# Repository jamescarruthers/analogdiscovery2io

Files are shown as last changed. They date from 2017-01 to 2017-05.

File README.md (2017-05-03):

# Interface board for Digilent Analog Discovery 2

**Rev-a has been tested and confirmed to work, Rev-b has not been tested yet**

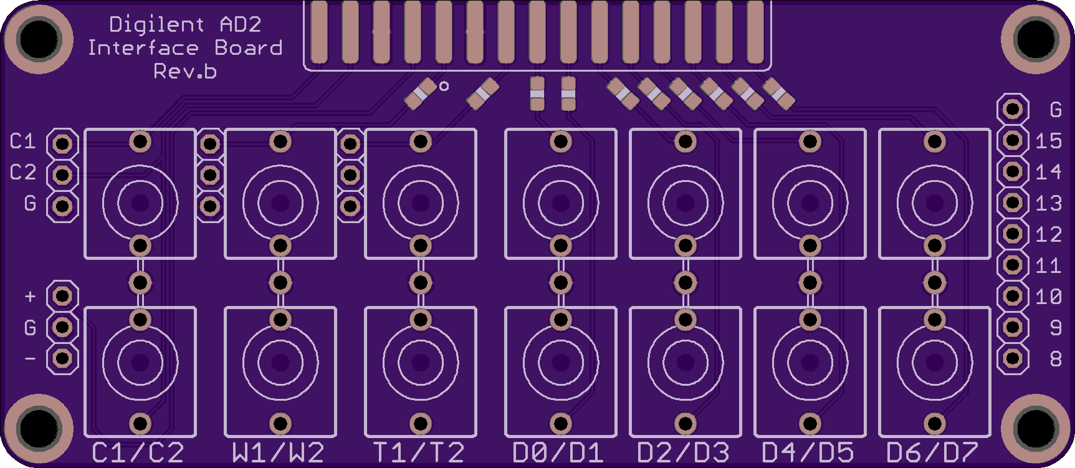
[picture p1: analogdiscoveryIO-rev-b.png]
Board rev-b


A board to interface anything that uses 3.5mm mono jacks (synthesisers etc) with the Digilent Analog Discovery 2 oscilloscope/wave generator/logic analyser.

Provides access to both scope channels, wave generators, triggers plus DIO 0 to 7 via 3.5mm mono jacks. DIO 8 to 15 and V+/V-/Ground via pin headers. The negative differential scope channels are connected to ground.

Note that the wave generator can output -+5V, however the DIO only 3.3V. This board does not implement any kind of level shifting, so if you're testing inputs with the output of the DIO channels then your module needs to work with 3.3V gates/triggers.

Connects directly to the AD2 with a female header. I made this as an edge connector — so you can use a 2x15 or two 1x15 straight headers.

Note; the digital I/O (including triggers) on the AD2 supports overvoltage up to -+20V. Rev-b includes resistors on all jack sockets except the scope channels. Suggest 1k on the wave generator (denoted with a dot) and 10k on the DIO.

There are 3mm holes in each corner for stand offs to support the board.

* 14 qty Thonkiconn jack sockets; https://www.thonk.co.uk/shop/3-5mm-jacks/
* 1 qty single row 15-pin female header (cheaper) -or- double row 2x15 female header (a bit more expensive)
* 4 qty 3x1 pin headers (female if you want to use male-male jumpers wires etc)
* 1 qty 9x1 pin headers (female if you want to use male-male jumpers wires etc)
* 2 qty 1k 0603 resistor
* 10 qty 10k 0603 resistor
* 4 x M3 stand offs plus screws

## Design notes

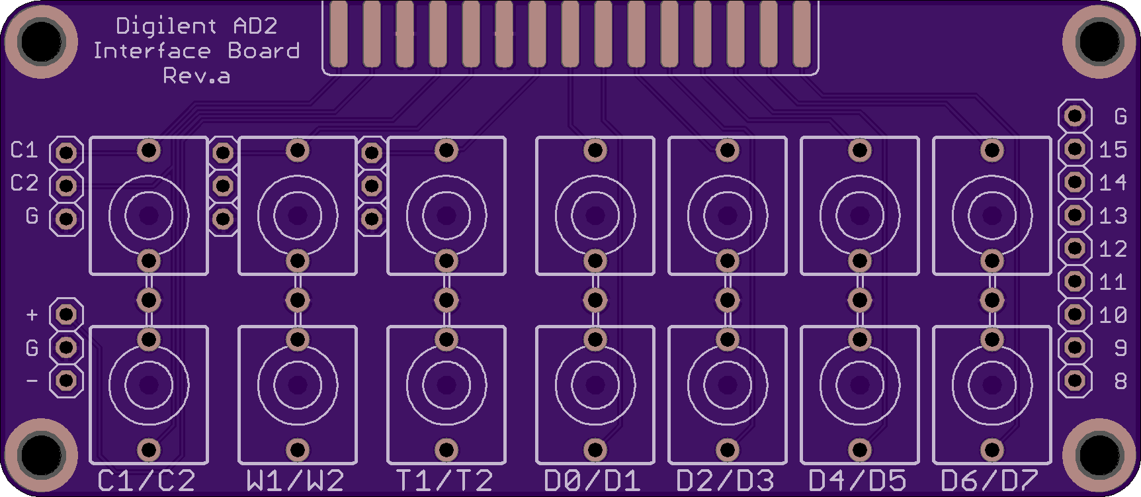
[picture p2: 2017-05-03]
analogdiscoveryIO-rev-a.png

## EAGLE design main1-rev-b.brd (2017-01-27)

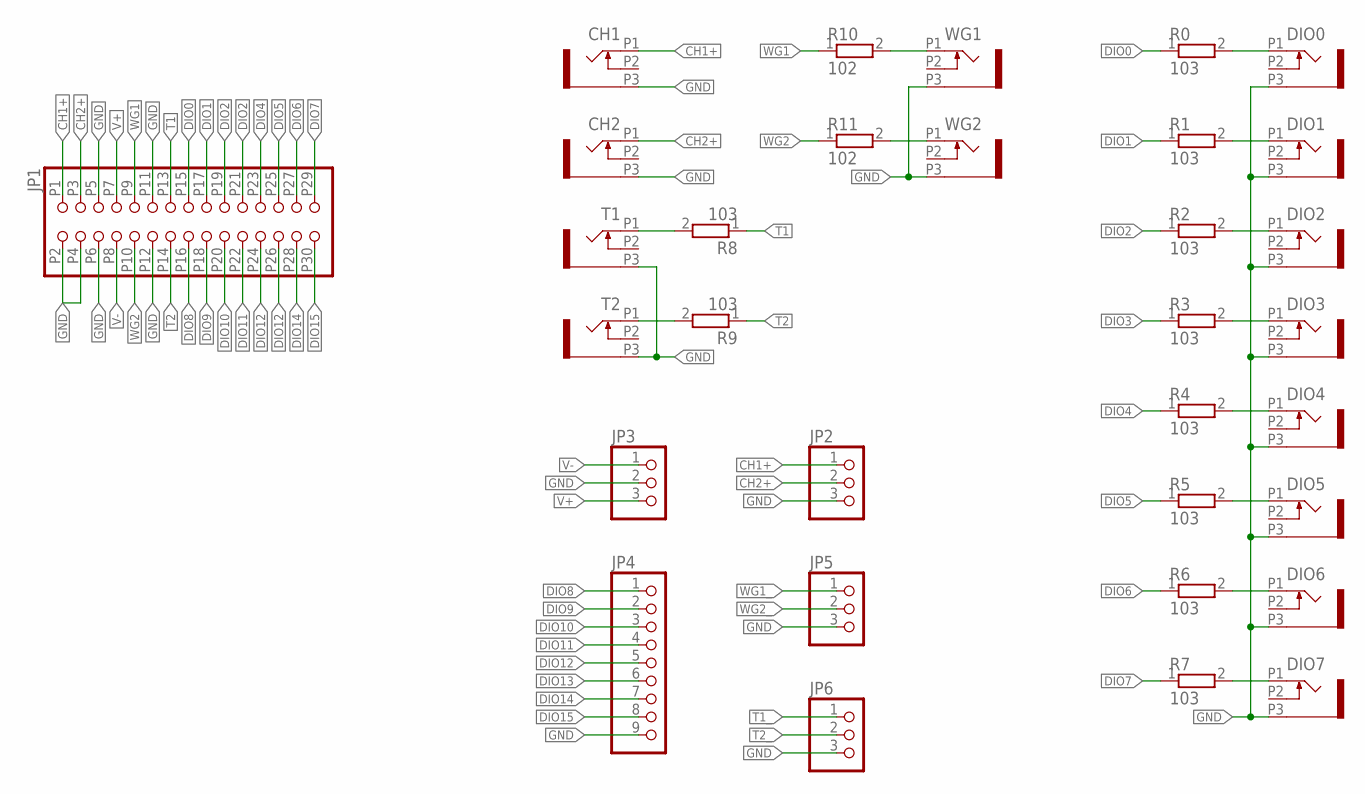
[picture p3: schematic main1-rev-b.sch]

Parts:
CH1, CH2: THONKICONN; WQP-PJ301M-12_JACK
DIO0, DIO1, DIO2, DIO3, DIO4, DIO5, DIO6, DIO7: THONKICONN; WQP-PJ301M-12_JACK
JP1: PINHD-2X15; 2X15/EDGE
JP2, JP3, JP5, JP6: PINHD-1X3/OCT; 1X03/OCT
JP4: PINHD-1X9/OCT; 1X09/OCT
R0, R1, R2, R3, R4, R5, R6, R7, R8, R9: 103; R0603
R10, R11: 102; R0603
T1, T2: THONKICONN; WQP-PJ301M-12_JACK
WG1, WG2: THONKICONN; WQP-PJ301M-12_JACK

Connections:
CH1+: CH1.P1 (2), JP1.P1 (1), JP2.1
CH2+: CH2.P1 (2), JP1.P3 (3), JP2.2
DIO0: JP1.P15 (15), R0.1
DIO0_: DIO0.P1 (2), R0.2
DIO1: JP1.P17 (17), R1.1
DIO1_: DIO1.P1 (2), R1.2
DIO2: JP1.P19 (19), R2.1
DIO2_: DIO2.P1 (2), R2.2
DIO3: JP1.P21 (21), R3.1
DIO3_: DIO3.P1 (2), R3.2
DIO4: JP1.P23 (23), R4.1
DIO4_: DIO4.P1 (2), R4.2
DIO5: JP1.P25 (25), R5.1
DIO5_: DIO5.P1 (2), R5.2
DIO6: JP1.P27 (27), R6.1
DIO6_: DIO6.P1 (2), R6.2
DIO7: JP1.P29 (29), R7.1
DIO7_: DIO7.P1 (2), R7.2
DIO8: JP1.P16 (16), JP4.1
DIO9: JP1.P18 (18), JP4.2
DIO10: JP1.P20 (20), JP4.3
DIO11: JP1.P22 (22), JP4.4
DIO12: JP1.P24 (24), JP4.5
DIO13: JP1.P26 (26), JP4.6
DIO14: JP1.P28 (28), JP4.7
DIO15: JP1.P30 (30), JP4.8
GND: CH1.P3 (1), CH2.P3 (1), DIO0.P3 (1), DIO1.P3 (1), DIO2.P3 (1), DIO3.P3 (1), DIO4.P3 (1), DIO5.P3 (1), DIO6.P3 (1), DIO7.P3 (1), JP1.P2 (2), JP1.P4 (4), JP1.P5 (5), JP1.P6 (6), JP1.P11 (11), JP1.P12 (12), JP2.3, JP3.2, JP4.9, JP5.3, JP6.3, T1.P3 (1), T2.P3 (1), WG1.P3 (1), WG2.P3 (1)
T1: JP1.P13 (13), R8.1
T1_: JP6.1, R8.2, T1.P1 (2)
T2: JP1.P14 (14), R9.1
T2_: JP6.2, R9.2, T2.P1 (2)
V+: JP1.P7 (7), JP3.3
V-: JP1.P8 (8), JP3.1
WG1: JP1.P9 (9), R10.1
WG1_: JP5.1, R10.2, WG1.P1 (2)
WG2: JP1.P10 (10), R11.1
WG2_: JP5.2, R11.2, WG2.P1 (2)

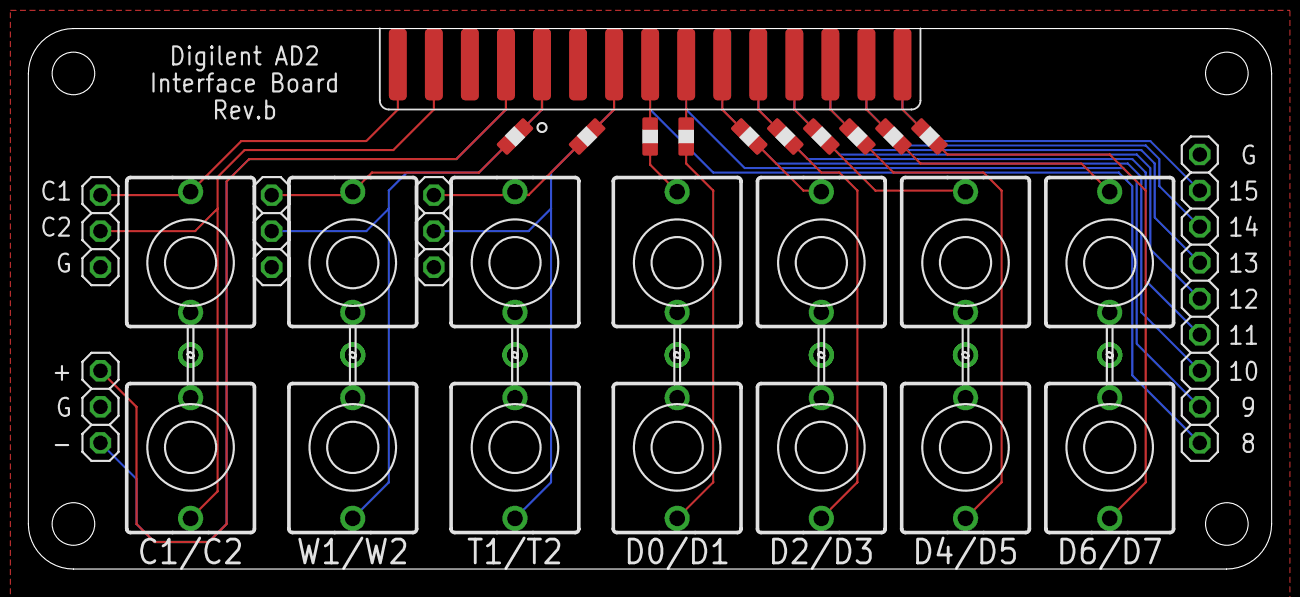
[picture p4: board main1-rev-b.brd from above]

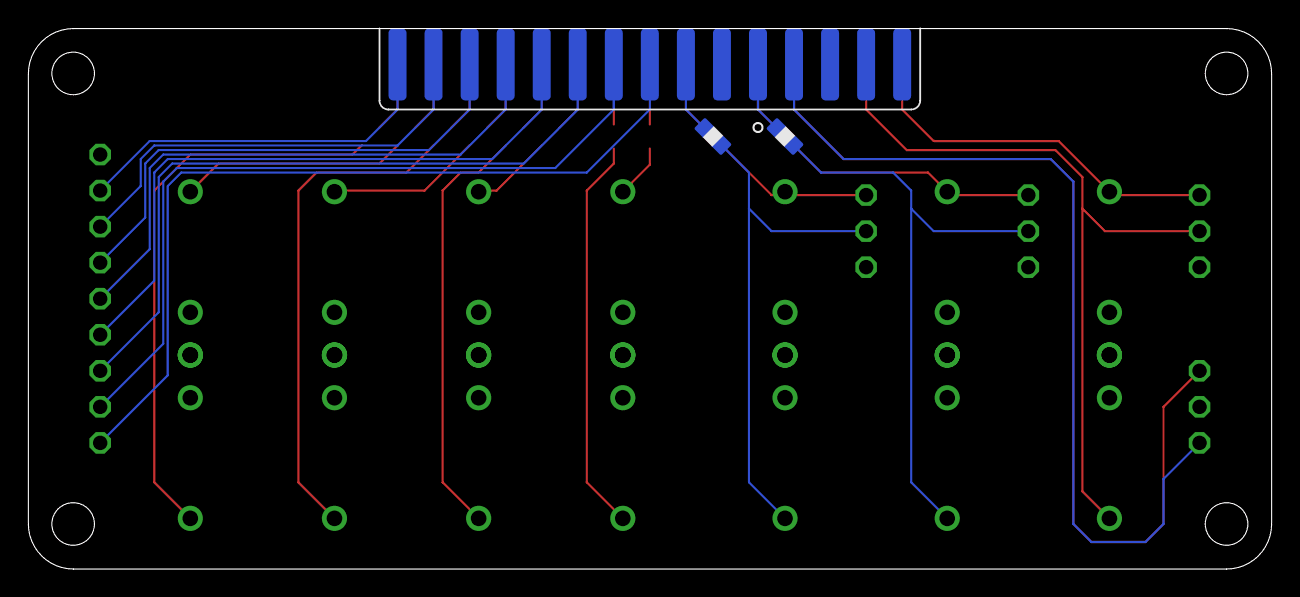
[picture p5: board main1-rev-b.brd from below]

Board: 2 copper layers, 87.6 x 38.1 mm, 36 parts (2 on the bottom side), 37 nets.

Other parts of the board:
U$1, U$2, U$3, U$4: HOLE_3MM
